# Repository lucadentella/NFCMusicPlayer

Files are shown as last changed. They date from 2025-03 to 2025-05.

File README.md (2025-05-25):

# NFCMusicPlayer

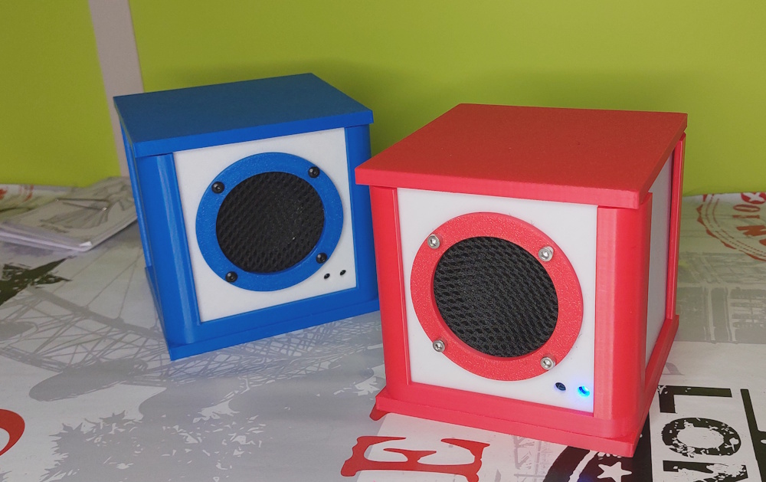
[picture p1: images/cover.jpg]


Portable MP3 music player with NFC tags control



## Features :trophy:

 - **SD card** reader
 - **Battery** powered with built-in **USB-C charger**
 - **Web based** configuration (map NFC tags to songs)
 - **Arduino** based firmware
 - **3D printed** enclosure

## :movie_camera: Tutorial
- [Youtube video - English](https://youtu.be/ck0IdwVWIIs)
- [Youtube video - Italiano](https://youtu.be/Wxny4k97sL8)

## :notebook: Documentation
 - [Part list](https://github.com/lucadentella/NFCMusicPlayer/tree/main/documentation/partlist.md)
 - [Some tips for building it](https://github.com/lucadentella/NFCMusicPlayer/tree/main/documentation/tips.md)
 - [Troubleshooting - Error codes](https://github.com/lucadentella/NFCMusicPlayer/tree/main/documentation/error-codes.md)

## :wrench: Board
- [Schematics, PDF](https://github.com/lucadentella/NFCMusicPlayer/raw/main/board/NFCMusicPlayer_12-sch.pdf)
- [KiCAD 8 files](https://github.com/lucadentella/NFCMusicPlayer/raw/main/board/)
- [SDcard content](https://github.com/lucadentella/NFCMusicPlayer/raw/main/sdcard/)
- [Project page for ready-made PCBs](https://www.pcbway.com/project/shareproject/NFCMusicPlayer_7cb0c6f8.html)
 
## :gift: Enclosure
- ["Thing" on Thingiverse](https://www.thingiverse.com/thing:6994529)

 ## :floppy_disk: Firmware
 - [Arduino sketch](https://github.com/lucadentella/NFCMusicPlayer/tree/main/firmware/NFCMusicPlayer)
 
**Required libraries**
- [ESP32-audioI2S](https://github.com/schreibfaul1/ESP32-audioI2S) 2.0.0
- [Adafruit_PN532](https://github.com/adafruit/Adafruit-PN532) 1.3.4
- [Async TCP](https://github.com/ESP32Async/AsyncTCP) 3.4.0
- [ESP Async WebServer](https://github.com/ESP32Async/ESPAsyncWebServer) 3.7.7
- [ArduinoJson](https://arduinojson.org/?utm_source=meta&utm_medium=library.properties) 7.4.1
- [Arduino List](https://github.com/nkaaf/Arduino-List) 3.0.1

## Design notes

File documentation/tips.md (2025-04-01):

# :mega: Tips

This page lists some tips to help building an NFCMusicPlayer

> Please refer to [Part list](https://github.com/lucadentella/NFCMusicPlayer/tree/main/documentation/partlist.md) page for the complete list of components.

### Fabric
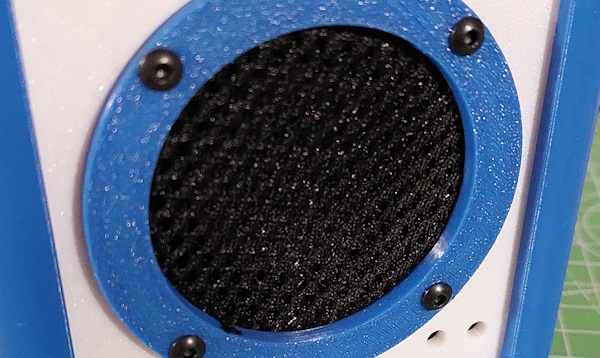
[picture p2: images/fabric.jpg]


My suggestion is to add some speaker fabric to protect your speaker (and for aesthetic reasons, it's much nicer that way ;)).

I ordered [this cloth](https://www.aliexpress.com/item/1005005824294055.html) from Aliexpress... it will last you a few dozen of NFCMusicPlayers!

### Voltage regulator
I needed a *low-dropout* 3.3V voltage regulator that could provide up to **1A** of current. I considered some switching regulators, but to keep the project as simple as possible, I opted for a **linear** regulator and the [MCP1826S](https://ww1.microchip.com/downloads/en/DeviceDoc/22057B.pdf) from Microchip was the ideal choice:
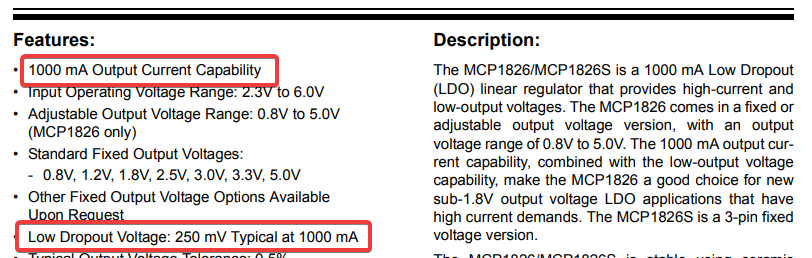
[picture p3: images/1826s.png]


You probably can source it from Aliexpress or lcsc.com.

### NFC tags
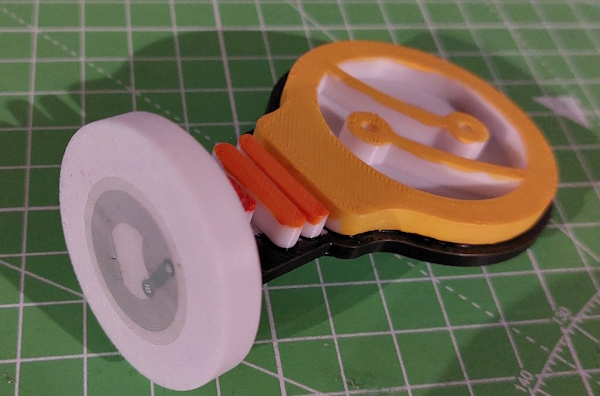
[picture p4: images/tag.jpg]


NFCMusicPlayer is compatible with all the tags the PN532 chip can read.
I ordered some [cards](https://www.aliexpress.com/item/1005006428199332.html) but I also loved the [stickers](https://www.aliexpress.com/item/1005005883601752.html) because you can stick them to objects (*figurines*, *toys*...) and play the corresponding track if the idem is placed on top of your player!

### Battery
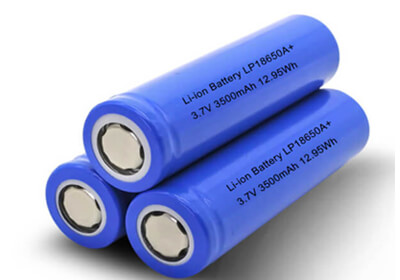
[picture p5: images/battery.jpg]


18650 lithium batteries are quite popular... with a capacity of 2000mAh I was able to play up to 10 hours of music before having to recharge it! 

### USB to serial adapter
It's very important to choose an USB to serial adapter with a working voltage of **3.3V**: you need it to program the firmware into the esp32 module and higher voltage will probably damage it!
Many adapters (like the [one I'm currently using](https://www.aliexpress.com/item/1005008182778961.html)) have a jumper or  microswitch to toggle between 5V and 3.3V... I suggest also to check with a multimeter the output voltage **before** connecting the adapter to the board to be safe!
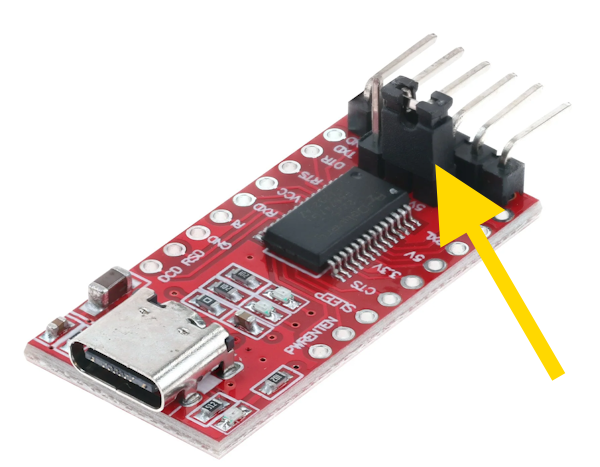
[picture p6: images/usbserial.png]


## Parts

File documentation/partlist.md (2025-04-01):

# :wrench: Part list

| ID | Description | Link | 
|--|--|--|
| R1 | Resistor, 10Kohm 1/4W | (n/a)
| R2, R3 | Resistor, 470ohm 1/4W | (n/a)
| R4 | Resistor, 27Kohm 1/4W | (n/a)
| R5 | Resistor, 100Kohm 1/4W | (n/a)
| R1 | Resistor, 470ohm 1/4W | (n/a)
| C1 | Capacitor, Electrolytic 10uF 25V | (n/a)
| C2 | Capacitor, Electrolytic 22uF 25V | (n/a)
| D1, D2 | 5mm LED | (n/a)
| RESET, BOOT | 6x6 PCB switch | [https://www.aliexpress.com/item/32960657626.htm](https://www.aliexpress.com/item/32960657626.htm)
| U1 | ESP32 WROOM-32E Module (4Mb) | [https://www.aliexpress.com/item/1005002032158386.html](https://www.aliexpress.com/item/1005002032158386.html)
| U2 | MCP1826S Voltage Regulator | (n/a)
||||
| M1 | 3.7V TP4056 Lithium Battery Charger Protect Type-C Board | [https://www.aliexpress.com/item/1445006612.html](https://www.aliexpress.com/item/1445006612.html)
| M3 | MAX98357A I2S 3W Class D Amplifier Breakout board | [https://www.aliexpress.com/item/1005006209483760.html](https://www.aliexpress.com/item/1005006209483760.html)
| M4 | Mini SD Module | [https://www.aliexpress.com/item/1005001861949506.html](https://www.aliexpress.com/item/1005001861949506.html)
| NFC | PN532 NFC RFID Wireless Module V3 | [https://www.aliexpress.com/item/1005001792108376.html](https://www.aliexpress.com/item/1005001792108376.html)
||||
| B1 | ABS 18650 1X Battery Holder | [https://www.aliexpress.com/item/1005001991113047.html](https://www.aliexpress.com/item/1005001991113047.html)
| BUTTON | SPST 16.3mm 2 Pin Round Switch  | [https://www.aliexpress.com/item/1005002032158386.html](https://www.aliexpress.com/item/1005005559022429.html)
| POT | RK097N 10Kohm potentiometer  | [https://www.aliexpress.com/item/1005001417073667.html](https://www.aliexpress.com/item/1005001417073667.html)
| SPEAKER | AIYIMA 2 Inch 4 Ohm 3W Full Range Speaker | [https://www.aliexpress.com/item/32593991938.html](https://www.aliexpress.com/item/32593991938.html)
||||
| CASE | 3D Printed Case | [https://www.thingiverse.com/](https://www.thingiverse.com/)
| INSERTS | M3 5x5mm Brass Inserts  | [https://www.aliexpress.com/item/1005003582355741.html](https://www.aliexpress.com/item/1005003582355741.html)
| SCREWS | M3 8mm, 10mm, 12mm | (n/a)

NOTE: Links are provided for reference only: most of the items are available on different stores

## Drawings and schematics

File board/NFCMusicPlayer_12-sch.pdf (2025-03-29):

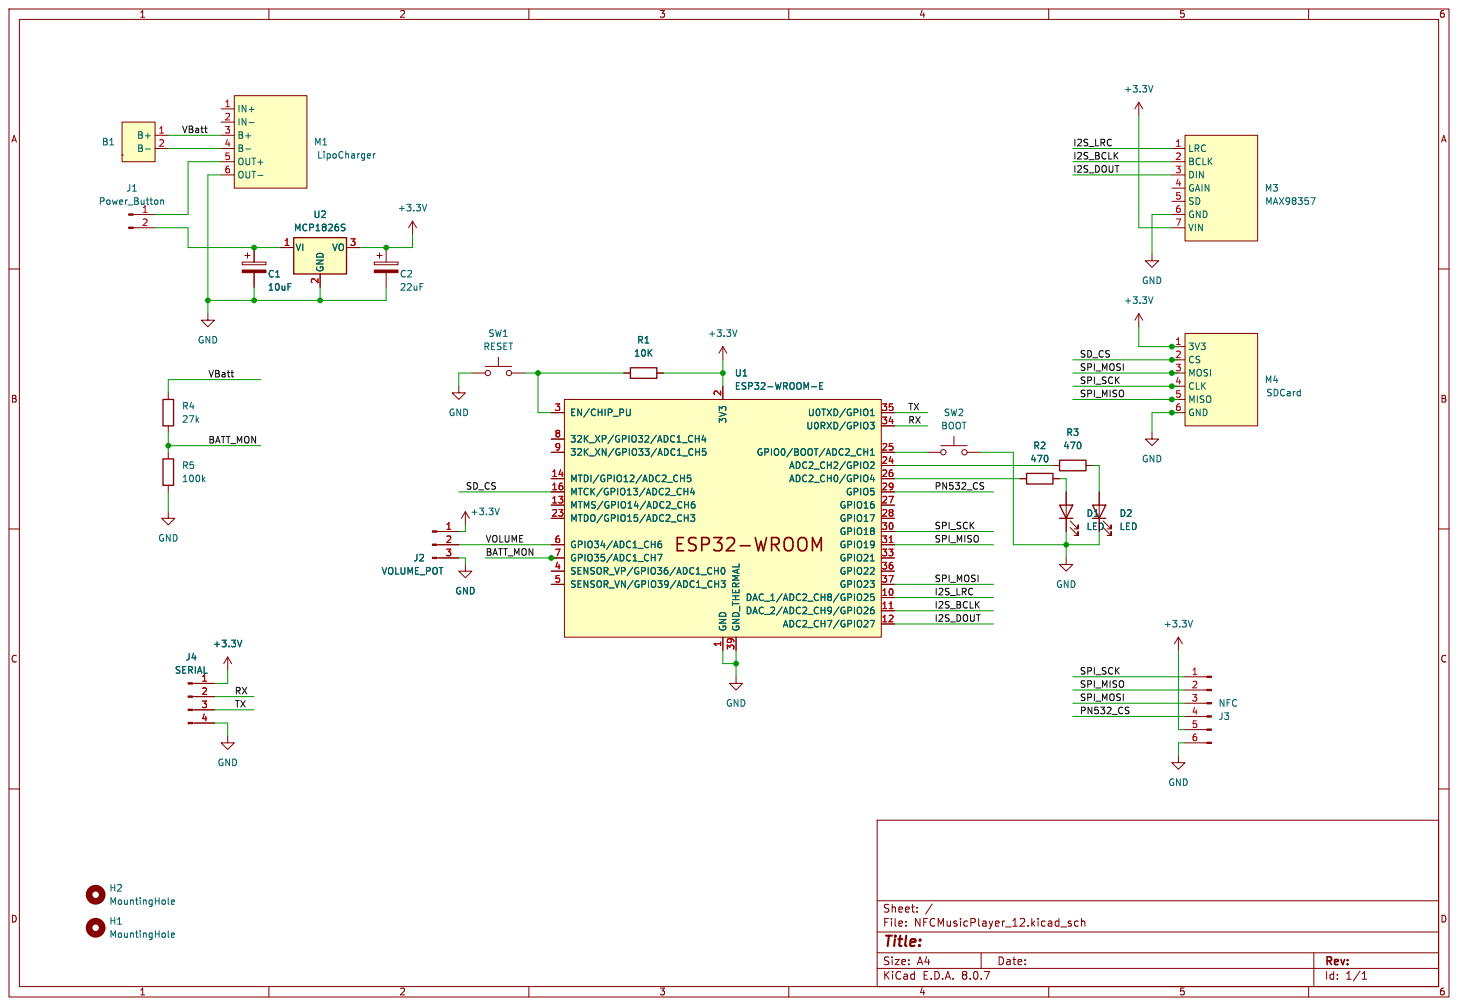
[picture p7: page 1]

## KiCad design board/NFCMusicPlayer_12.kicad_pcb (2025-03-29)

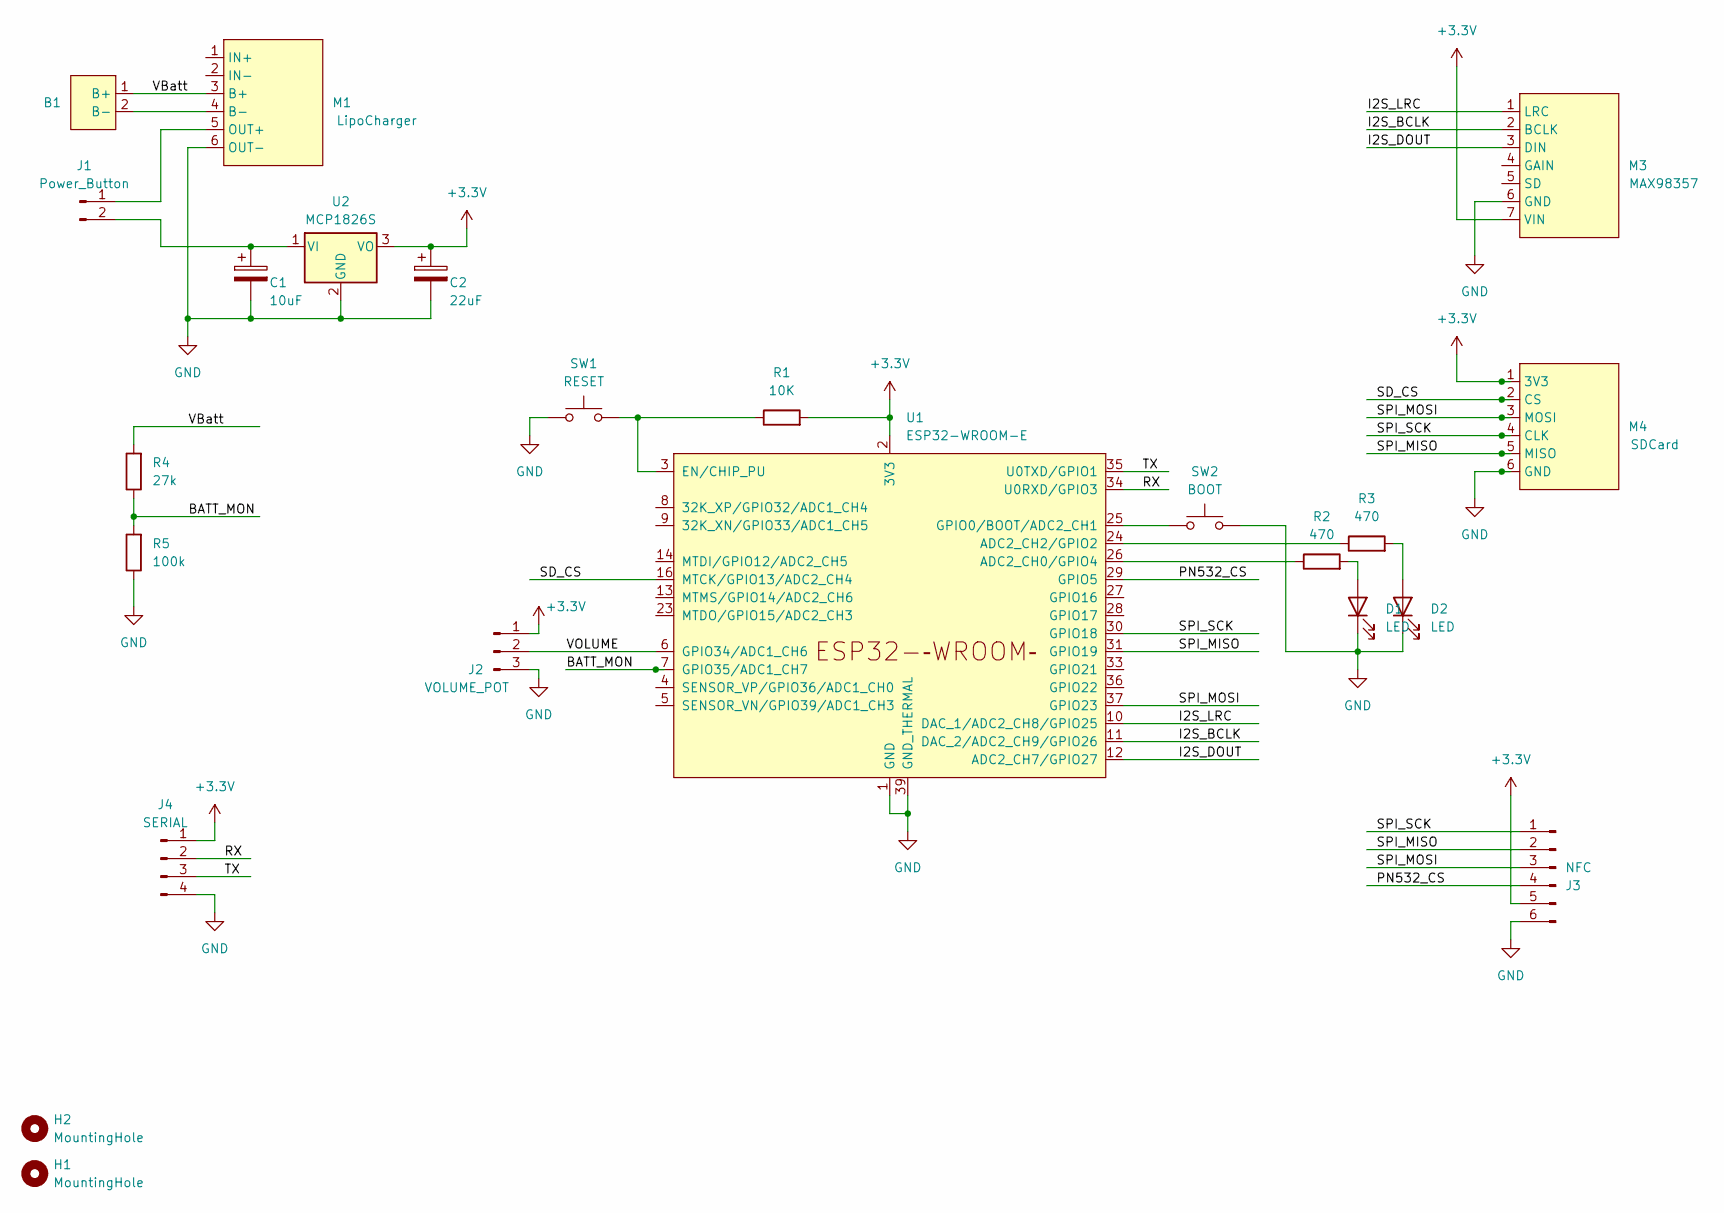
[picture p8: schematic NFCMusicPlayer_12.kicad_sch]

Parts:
B1: Battery_Holder
C1: 10uF; CP_Radial_D6.3mm_P2.50mm
C2: 22uF; CP_Radial_D6.3mm_P2.50mm
D1, D2: LED; LED_D5.0mm_Horizontal_O1.27mm_Z9.0mm
H1, H2: MountingHole; MountingHole_3.2mm_M3
J1: Power_Button; PinHeader_1x02_P2.54mm_Vertical
J2: VOLUME_POT; PinHeader_1x03_P2.54mm_Vertical
J3: NFC; PinHeader_1x06_P2.54mm_Vertical
J4: SERIAL; PinHeader_1x04_P2.54mm_Vertical
M1: LipoCharger; LipoCharger_Module
M3: MAX98357; MAX98357_Module
M4: SDCard; MicroSD_Module
R1: 10K; R_Axial_DIN0207_L6.3mm_D2.5mm_P2.54mm_Vertical
R2, R3: 470; R_Axial_DIN0207_L6.3mm_D2.5mm_P2.54mm_Vertical
R4: 27k; R_Axial_DIN0207_L6.3mm_D2.5mm_P2.54mm_Vertical
R5: 100k; R_Axial_DIN0207_L6.3mm_D2.5mm_P2.54mm_Vertical
SW1: RESET; SW_PUSH_6mm_H5mm
SW2: BOOT; SW_PUSH_6mm_H5mm
U1: ESP32-WROOM-E; ESP32-WROOM-32E
U2: MCP1826S; TO-220-3_Vertical

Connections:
+3.3V: C2.1, J2.1, J3.5, J4.1, M3.7 (VIN), M4.1 (3V3), R1.2, U1.2 (3V3), U2.3 (VO)
/BATT_MON: R4.1, R5.2, U1.7 (GPIO35/ADC1_CH7)
/I2S_BCLK: M3.2 (BCLK), U1.11 (DAC_2/ADC2_CH9/GPIO26)
/I2S_DOUT: M3.3 (DIN), U1.12 (ADC2_CH7/GPIO27)
/I2S_LRC: M3.1 (LRC), U1.10 (DAC_1/ADC2_CH8/GPIO25)
/PN532_CS: J3.4, U1.29 (GPIO5)
/RX: J4.2, U1.34 (U0RXD/GPIO3)
/SD_CS: M4.2 (CS), U1.16 (MTCK/GPIO13/ADC2_CH4)
/SPI_MISO: J3.2, M4.5 (MISO), U1.31 (GPIO19)
/SPI_MOSI: J3.3, M4.3 (MOSI), U1.37 (GPIO23)
/SPI_SCK: J3.1, M4.4 (CLK), U1.30 (GPIO18)
/TX: J4.3, U1.35 (U0TXD/GPIO1)
/VBatt: B1.1 (B+), M1.3 (B+), R4.2
/VOLUME: J2.2, U1.6 (GPIO34/ADC1_CH6)
GND: C1.2, C2.2, D1.1 (K), D2.1 (K), J2.3, J3.6, J4.4, M1.6 (OUT-), M3.6 (GND), M4.6 (GND), R5.1, SW1.1, SW2.2, U1.1 (GND), U1.15 (GND), U1.38 (GND), U1.39 (GND_THERMAL), U2.2 (GND)
unnamed: B1.2 (B-), M1.4 (B-)
unnamed: D1.2 (A), R2.2
unnamed: D2.2 (A), R3.2
unnamed: J1.1, M1.5 (OUT+)
unnamed: C1.1, J1.2, U2.1 (VI)
unnamed: R2.1, U1.26 (ADC2_CH0/GPIO4)
unnamed: R3.1, U1.24 (ADC2_CH2/GPIO2)
unnamed: R1.1, SW1.2, U1.3 (EN/CHIP_PU)
unnamed: SW2.1, U1.25 (GPIO0/BOOT/ADC2_CH1)

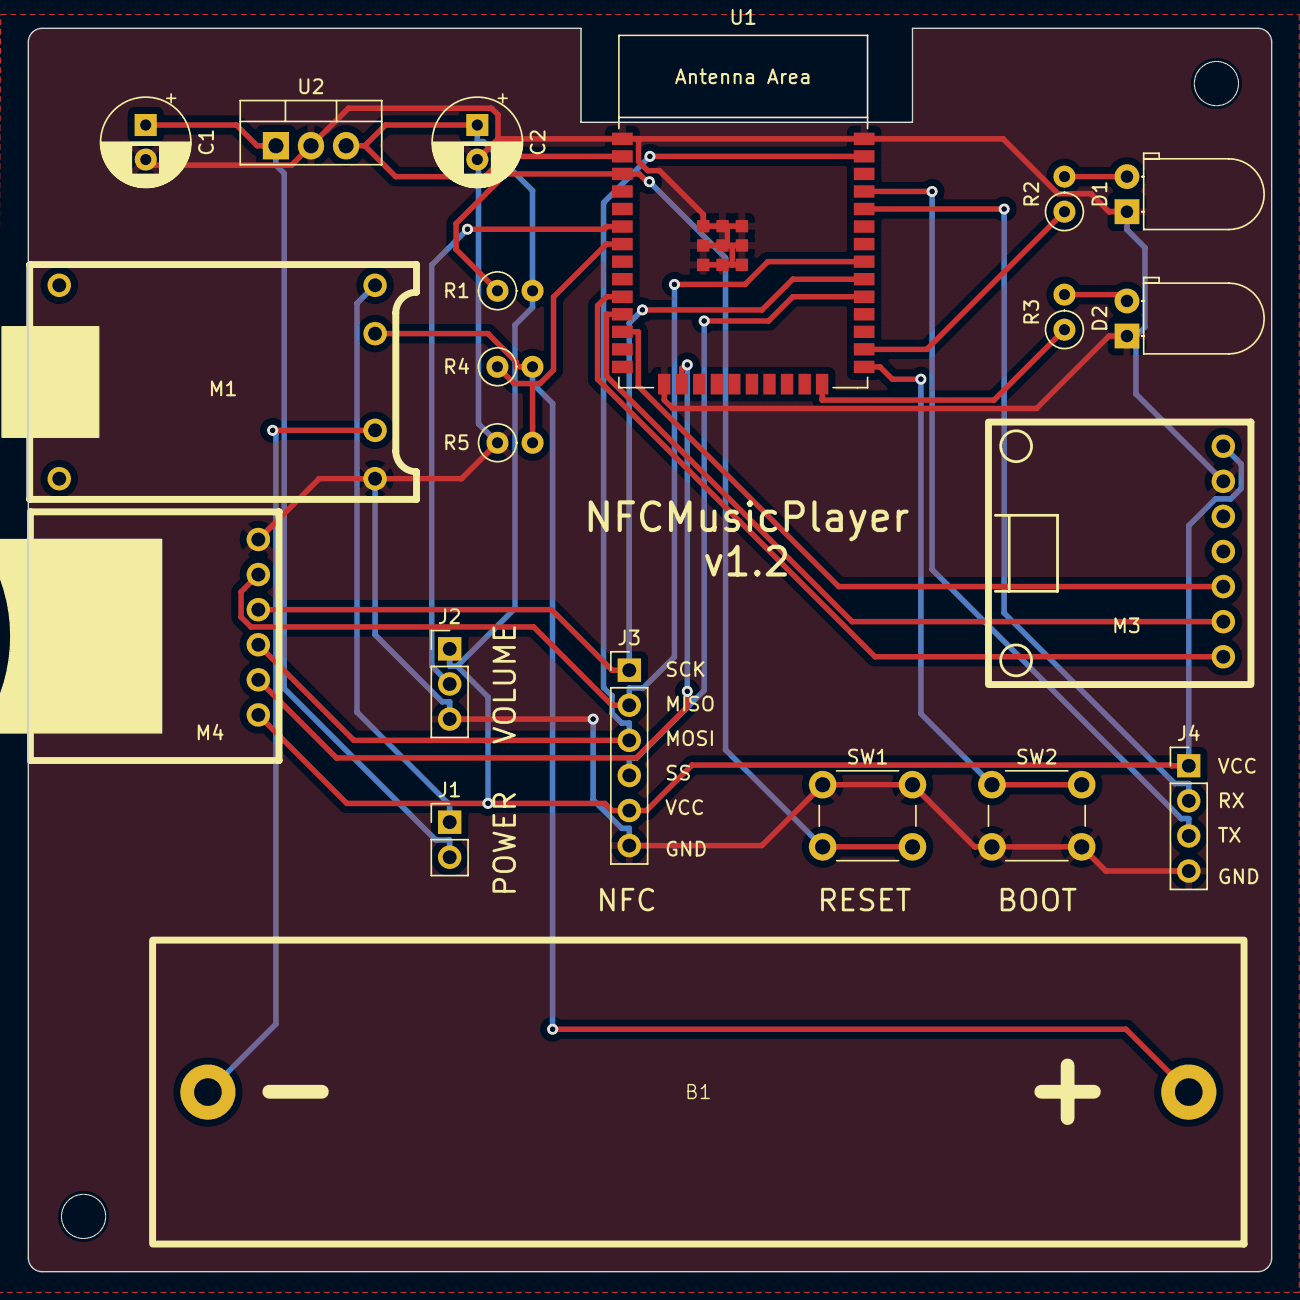
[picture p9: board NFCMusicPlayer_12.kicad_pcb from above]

Board: 2 copper layers, 90.0 x 90.0 mm, 23 parts (0 on the bottom side), 24 nets.

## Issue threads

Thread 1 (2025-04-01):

Some things missing from parts list

gwilymdavies, 2025-04-01:
I love the project.
I've tried to buy the items but there are some parts missing from the bill of materials.
I am not confident about specifying these myself so it would be great to have these detailed in the project:
-PCB switches
-battery
-USB to serial programmer (not technically part of the project but useful to know)
-do you know the specs for additional NFC tags, so we can get more at once?

Here are some more I am more confident with, but it would be useful to have links to them just in case:
-SD card
-speaker fabric
-do you have the specs for the LEDs?
-can you share a link for the voltage regulator?

Thank you.

lucadentella, 2025-04-01:
Hi

thanks for opening the issue, I'm adding a "tips" page to address your questions

Closed 2025-04-01.

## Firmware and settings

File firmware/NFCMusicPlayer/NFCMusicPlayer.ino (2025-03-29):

#include "NFCMusicPlayer.h"

void setup() {

  Serial.begin(115200);
  Serial.println("NFCMusicPlayer starting...");
  Serial.println();

  // Brownout
  WRITE_PERI_REG(RTC_CNTL_BROWN_OUT_REG, 0);
  Serial.println("- Brownout disabled");

  // PINs
  pinMode(STATUS_LED, OUTPUT);
  pinMode(PLAY_LED, OUTPUT);
  pinMode(VOLUME_PIN, INPUT);
  Serial.println("- PINs configured");

  // Check SD card, blink in case of error
  spi.begin(SPI_SCK, SPI_MISO, SPI_MOSI);
  if (!SD.begin(SD_CS, spi, 80000000)) {
    Serial.println("! Unable to mount SD card");
    while(1) {
      digitalWrite(STATUS_LED, HIGH);
      delay(1000);
      digitalWrite(STATUS_LED, LOW);
      delay(1000);     
    }
  }
  uint64_t cardSize = SD.cardSize() / (1024 * 1024);
  Serial.printf("- SD card OK, size: %lluMB\n", cardSize);

  // Load mappings from SD card
  readMappings();
  Serial.println("- Mappings loaded from SD card");

  // Check PN532 board, blink faster in case of error
  nfc.begin();
  uint32_t versiondata = nfc.getFirmwareVersion();
  if(!versiondata) {
    Serial.println("! Unable to find PN532 board");
    while(1) {
      digitalWrite(STATUS_LED, HIGH);
      delay(200);
      digitalWrite(STATUS_LED, LOW);
      delay(200);     
    }
  }
  Serial.printf("- PN532 board OK, firmware: %d\n", (versiondata>>16) & 0xFF);

  // Run WiFi in AccessPoint MODE
  WiFi.softAP(AP_SSID, AP_PASSWORD);
  IPAddress IP = WiFi.softAPIP();
  Serial.print("- AccessPoint running: ");
  Serial.println(IP);

  // Configure and start webserver
  initWebserver();
  Serial.println("- Webserver running");

  // Configure Audio library
  audio.setPinout(I2S_BCLK, I2S_LRC, I2S_DOUT);
  audio.setVolumeSteps(20);
  audio.setVolume(currentVolume);
  audio.setTone(10, 0, 0);
  Serial.println("- Audio library OK");

  // Start NFC task
  xTaskCreate(nfcTaskCode, "nfcTask", 10000, NULL, tskIDLE_PRIORITY, &nfcTaskHandler);
  Serial.println("- NFC task created");

  // Ready to play!
  digitalWrite(STATUS_LED, HIGH);
  Serial.println();
  Serial.println("...NFCMusicPlayer READY :)");
}

void loop() {

  // Audio library required loop
  audio.loop();

  // Check volume (average value every VOLUME_SAMPLES samples)
  int potValue = analogRead(VOLUME_PIN);
  volumeSamplesSum += potValue;
  volumeSamples++;
  if(volumeSamples == VOLUME_SAMPLES) {
    int newVolume = map(volumeSamplesSum / VOLUME_SAMPLES, 0, 4095, 0, 20);
    if(newVolume != currentVolume) {
      currentVolume = newVolume;
      audio.setVolume(currentVolume);
      Serial.printf("Volume changed to: %d\n", currentVolume);
    }
    volumeSamplesSum = 0;
    volumeSamples = 0;
  }
}

// NFC Task: check if a NFC tag is present
void nfcTaskCode(void * pvParameters) {

  for(;;) {
    long currentTime = millis();
    if(currentTime - lastReadTime > NFC_READ_INTERVAL) {
    
      uint8_t success;
      uint8_t uid[] = { 0, 0, 0, 0, 0, 0, 0 };
      uint8_t uidLength;
      success = nfc.readPassiveTargetID(PN532_MIFARE_ISO14443A, uid, &uidLength, 1500);
      
      if (success) {
        
        nfcPresent = true;
        // Save the nfcUID in the form AA:BB:CC:DD...
        tagID = "";
        for(int i = 0; i < uidLength; i++) {
          if(uid[i] <= 0xF) tagID += "0";
          tagID += String(uid[i] & 0xFF, HEX);
          if(i < (uidLength - 1)) tagID += ":";
          
        }
        Serial.printf("Tag found, %S\n", tagID.c_str());       

        if(!playing) {
          
          // Find in the mappings the song to be played
          for(int i = 0; i < mappings.getSize(); i++) {
            if(tagID.equals(mappings[i].tagid)) {
              char songPath[255];
              sprintf(songPath, "%s/%s", MUSIC_FOLDER,mappings[i].song.c_str());
              Serial.printf("Tag found, playing %s\n", songPath);
              audio.connecttoFS(SD, songPath);
              playing = true;
              digitalWrite(PLAY_LED, HIGH);
              break;
            }
          }
        }
      }
      
      else {
        
        nfcPresent = false;
        if(playing) {
          Serial.println("Tag not found, stop playing");
          audio.stopSong();
          playing = false;
          digitalWrite(PLAY_LED, LOW);
        }
      }
      lastReadTime = currentTime;
    }
  }
}

// Callback at the end of the song
void audio_eof_mp3(const char *info){  //end of file
    Serial.println("End of song");
    playing = false;
    digitalWrite(PLAY_LED, LOW);
}

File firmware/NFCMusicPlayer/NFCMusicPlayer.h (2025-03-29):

// Required libraries
#include <Audio.h>
#include <FS.h>
#include <SD.h>
#include <SPI.h>
#include <Adafruit_PN532.h>
#include <WiFi.h>
#include <AsyncTCP.h>
#include <ESPAsyncWebSrv.h>
#include <ArduinoJson.h>
#include <AsyncJson.h>
#include <List.hpp>

// to disable brownout
#include "soc/soc.h"
#include "soc/rtc_cntl_reg.h"

// PINs
#define SD_CS         13
#define PN532_CS      5
#define SPI_MOSI      23//15
#define SPI_MISO      19//2
#define SPI_SCK       18//14
#define I2S_DOUT      27//16
#define I2S_BCLK      26
#define I2S_LRC       25
#define PLAY_LED      2
#define STATUS_LED    4
#define VOLUME_PIN    34
#define BATTERY_PIN   35

// Configuration
#define NFC_READ_INTERVAL   2000
#define VOLUME_SAMPLES      200
#define MAX_SLOTS           20
#define MAPPINGS_FILE       "/mappings.txt"
#define MUSIC_FOLDER        "/music"
#define WEBUI_FOLDER        "/web/"
#define AP_SSID             "NFCMusicPlayer"
#define AP_PASSWORD         "MyMusicPlayer"


// Struct and array for mapping between tags and songs
typedef struct {
  String tagid;
  String song;
} mapping;
List<mapping> mappings;

// Global objects
SPIClass spi = SPIClass(VSPI);
Adafruit_PN532 nfc(PN532_CS, &spi);
Audio audio;
AsyncWebServer server(80);

// Global variables
TaskHandle_t nfcTaskHandler;
String tagID;
bool nfcPresent = false;
bool playing = false;
long lastReadTime = -1;
long volumeSamplesSum = 0;
int volumeSamples = 0;
int currentVolume = 10;

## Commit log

2025-03-29 Project updated
    [NFCMusicPlayer_12.kicad_pcb, NFCMusicPlayer_12.kicad_sch]
2026-01-26 imporved web interface, changes for volume (#4)
    * Add PlatformIO support and fix compatibility issues
    - Add platformio.ini for PlatformIO build system
    - Restructure source files to src/ directory (PlatformIO convention)
    - Fix header include: ESPAsyncWebSrv.h -> ESPAsyncWebServer.h
    - Comment out audio.setVolumeSteps() (not available in v2.0.6+)
    - Add CLAUDE.md documentation for future development
    - Add .gitignore for build artifacts
    * Fix NFC detection and optimize power consumption
    - Fix brownout issues by optimizing PN532 RF power
    - Reduce scan timeout to 1000ms f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

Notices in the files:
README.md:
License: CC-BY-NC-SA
